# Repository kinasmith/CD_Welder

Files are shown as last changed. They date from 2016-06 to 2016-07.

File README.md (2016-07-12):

##Capacitive Discharge Welder

based off of this [project.](http://www.instructables.com/id/Capacitive-Discharge-CD-Welder-for-battery-tabs/) and this [project](http://zeva.com.au/Projects/SpotWelderV2/). 

Included in this repo is the Control code (for arduino Pro Mini), and the PCB files I used. The Capacitor Board is slightly too large for the free version of Eagle (sorry!).

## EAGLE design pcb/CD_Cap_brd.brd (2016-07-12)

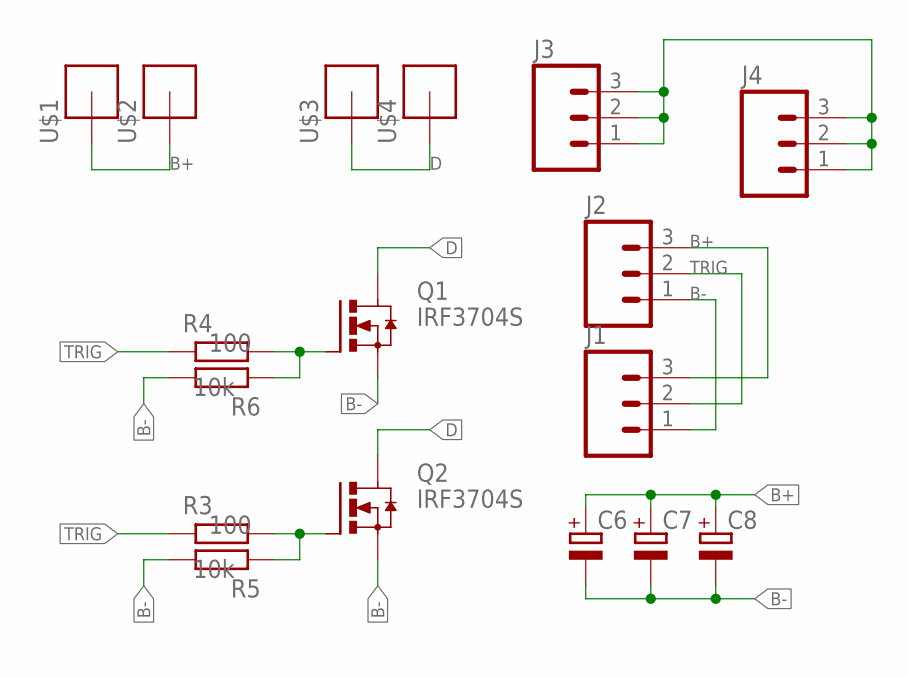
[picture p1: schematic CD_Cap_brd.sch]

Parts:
C6, C7, C8: CPOL-EUE10-35; EB35D
J1, J2: M03PTH; 1X03
J3, J4: M03LOCK; 1X03_LOCK
Q1, Q2: IRF3704S; D2PACK
R3, R4: 100; R0603-N
R5, R6: 10k; R0603-N
U$1, U$2, U$3, U$4: BIG_PINHEADX110-32; M6_PINHEAD

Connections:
B+: C6.+, C7.+, C8.+, J1.3, J2.3, U$1.P$1, U$2.P$1
B-: C6.-, C7.-, C8.-, J1.1, J2.1, J3.1, J3.2, J3.3, J4.1, J4.2, J4.3, Q1.3 (S), Q2.3 (S), R5.2, R6.2
D: Q1.2 (D), Q2.2 (D), U$3.P$1, U$4.P$1
unnamed: Q1.1 (G), R4.2, R6.1
unnamed: Q2.1 (G), R3.2, R5.1
TRIG: J1.2, J2.2, R3.1, R4.1

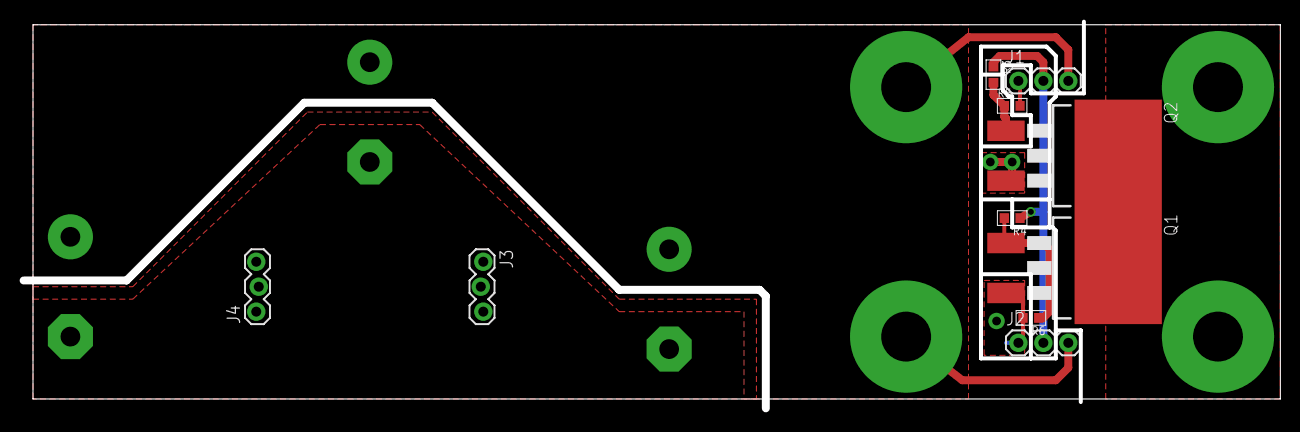
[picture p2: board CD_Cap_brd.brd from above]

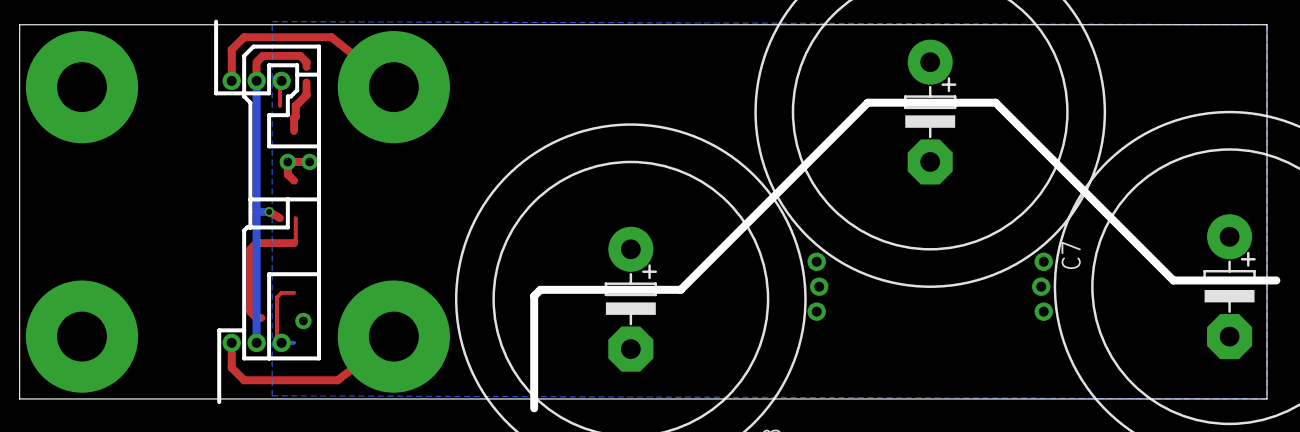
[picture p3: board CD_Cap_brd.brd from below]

Board: 2 copper layers, 128.0 x 39.4 mm, 17 parts (3 on the bottom side), 6 nets.

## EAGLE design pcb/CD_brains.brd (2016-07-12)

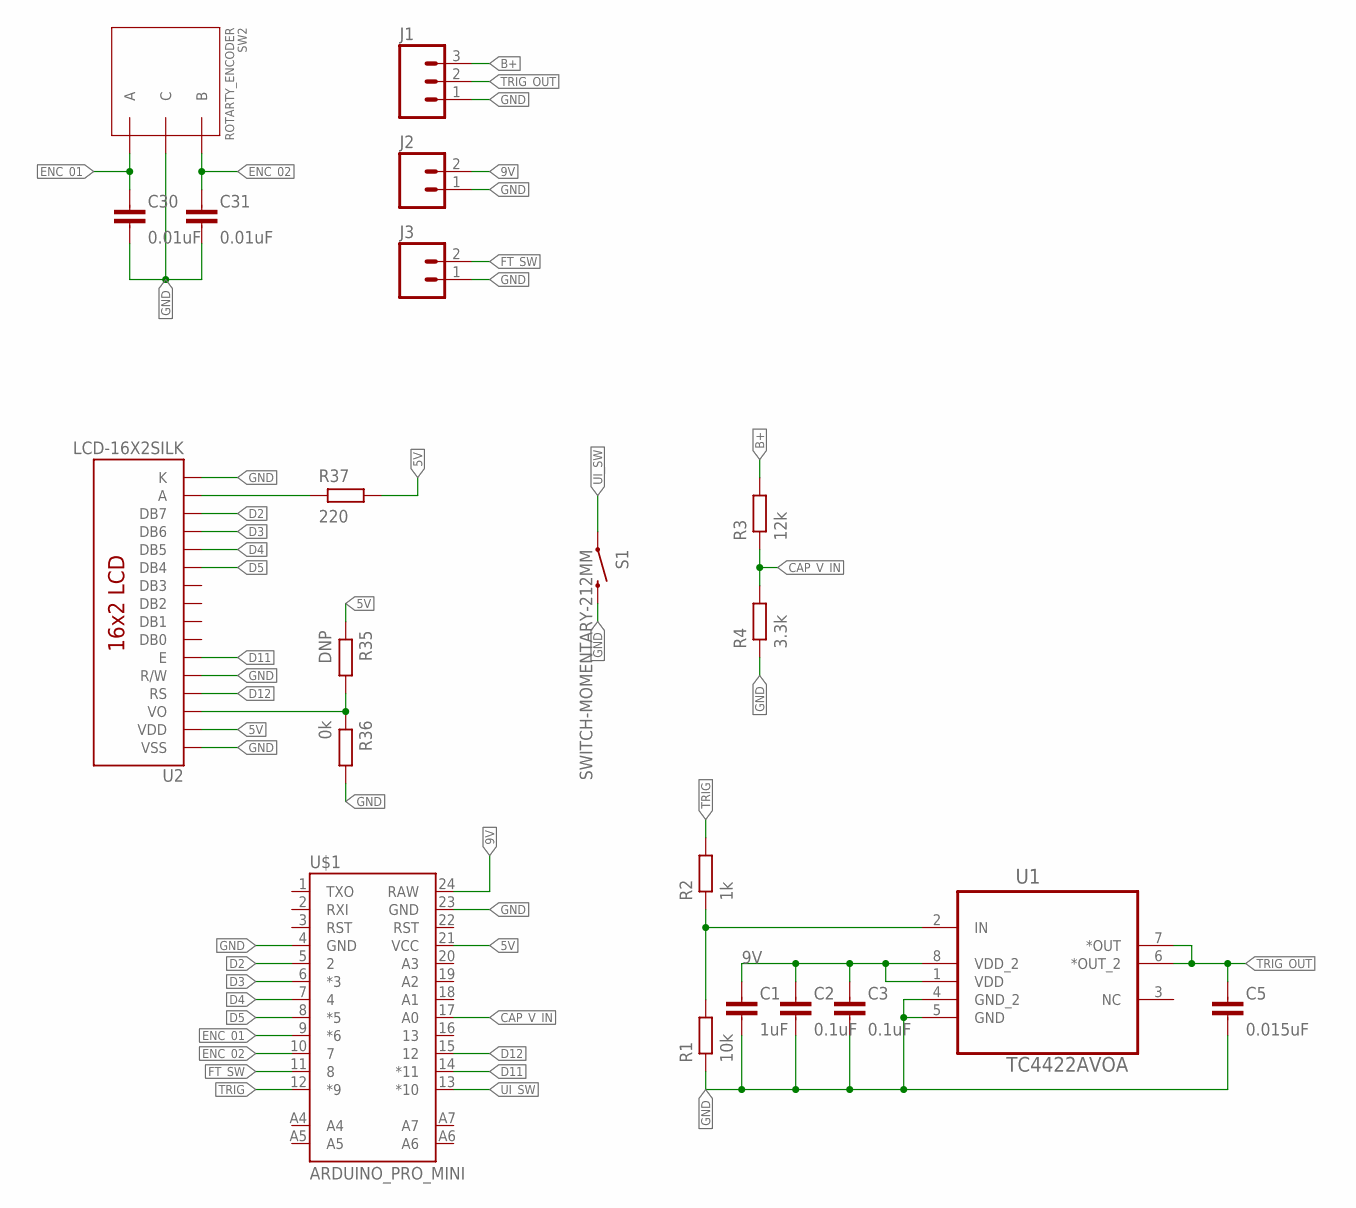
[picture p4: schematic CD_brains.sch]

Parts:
C1: 1uF; C0805-N
C2, C3: 0.1uF; C0603-N
C5: 0.015uF; C0603-N
C30, C31: 0.01uF; C0603-N
J1: M03LOCK_NO_SILK; 1X03_LOCK_NO_SILK
J2, J3: M02LOCK; 1X02_LOCK
R1: 10k; R0603-N
R2: 1k; R0603-N
R3: 12k; R0603-N
R4: 3.3k; R0603-N
R35: DNP; R0603-N
R36: 0k; R0603-N
R37: 220; R0603-N
S1: SWITCH-MOMENTARY-212MM; TACTILE-PTH-12MM
SW2: ROTARTY_ENCODER; ROTARY_ENC_PLAIN
U1: TC4422AVOA; SOIC127P600X175-8N
U2: LCD-16X2SILK; LCD-16X2
U$1: ARDUINO_PRO_MINI

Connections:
5V: R35.1, R37.2, U2.2 (VDD), U$1.21 (VCC)
9V: C1.1, C2.1, C3.1, J2.2, U1.1 (VDD), U1.8 (VDD_2), U$1.24 (RAW)
B+: J1.3, R3.2
CAP_V_IN: R3.1, R4.2, U$1.17 (A0)
D2: U2.14 (DB7), U$1.5 (2)
D3: U2.13 (DB6), U$1.6 (*3)
D4: U2.12 (DB5), U$1.7 (4)
D5: U2.11 (DB4), U$1.8 (*5)
D11: U2.6 (E), U$1.14 (*11)
D12: U2.4 (RS), U$1.15 (12)
ENC_01: C30.1, SW2.A, U$1.9 (*6)
ENC_02: C31.1, SW2.B, U$1.10 (7)
FT_SW: J3.2, U$1.11 (8)
GND: C1.2, C2.2, C3.2, C5.2, C30.2, C31.2, J1.1, J2.1, J3.1, R1.1, R4.1, R36.2, S1.3 (2), SW2.C, U1.4 (GND_2), U1.5 (GND), U2.1 (VSS), U2.5 (R/W), U2.16 (K), U$1.4 (GND), U$1.23 (GND)
unnamed: R1.2, R2.1, U1.2 (IN)
unnamed: R37.1, U2.15 (A)
unnamed: R35.2, R36.1, U2.3 (VO)
TRIG: R2.2, U$1.12 (*9)
TRIG_OUT: C5.1, J1.2, U1.6 (*OUT_2), U1.7 (*OUT)
UI_SW: S1.1, U$1.13 (*10)

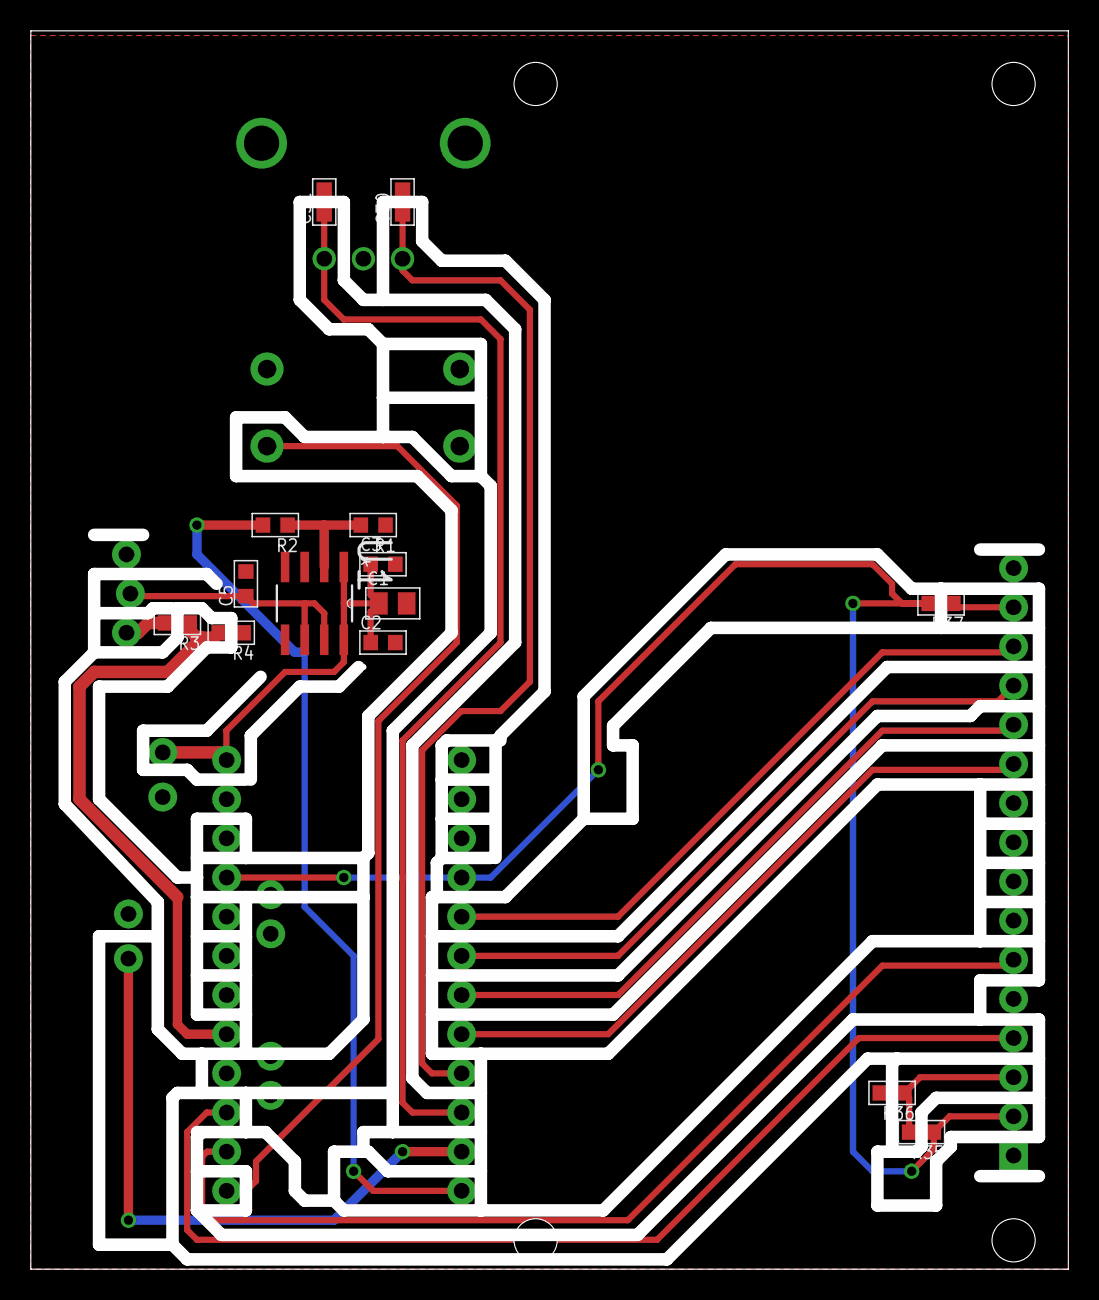
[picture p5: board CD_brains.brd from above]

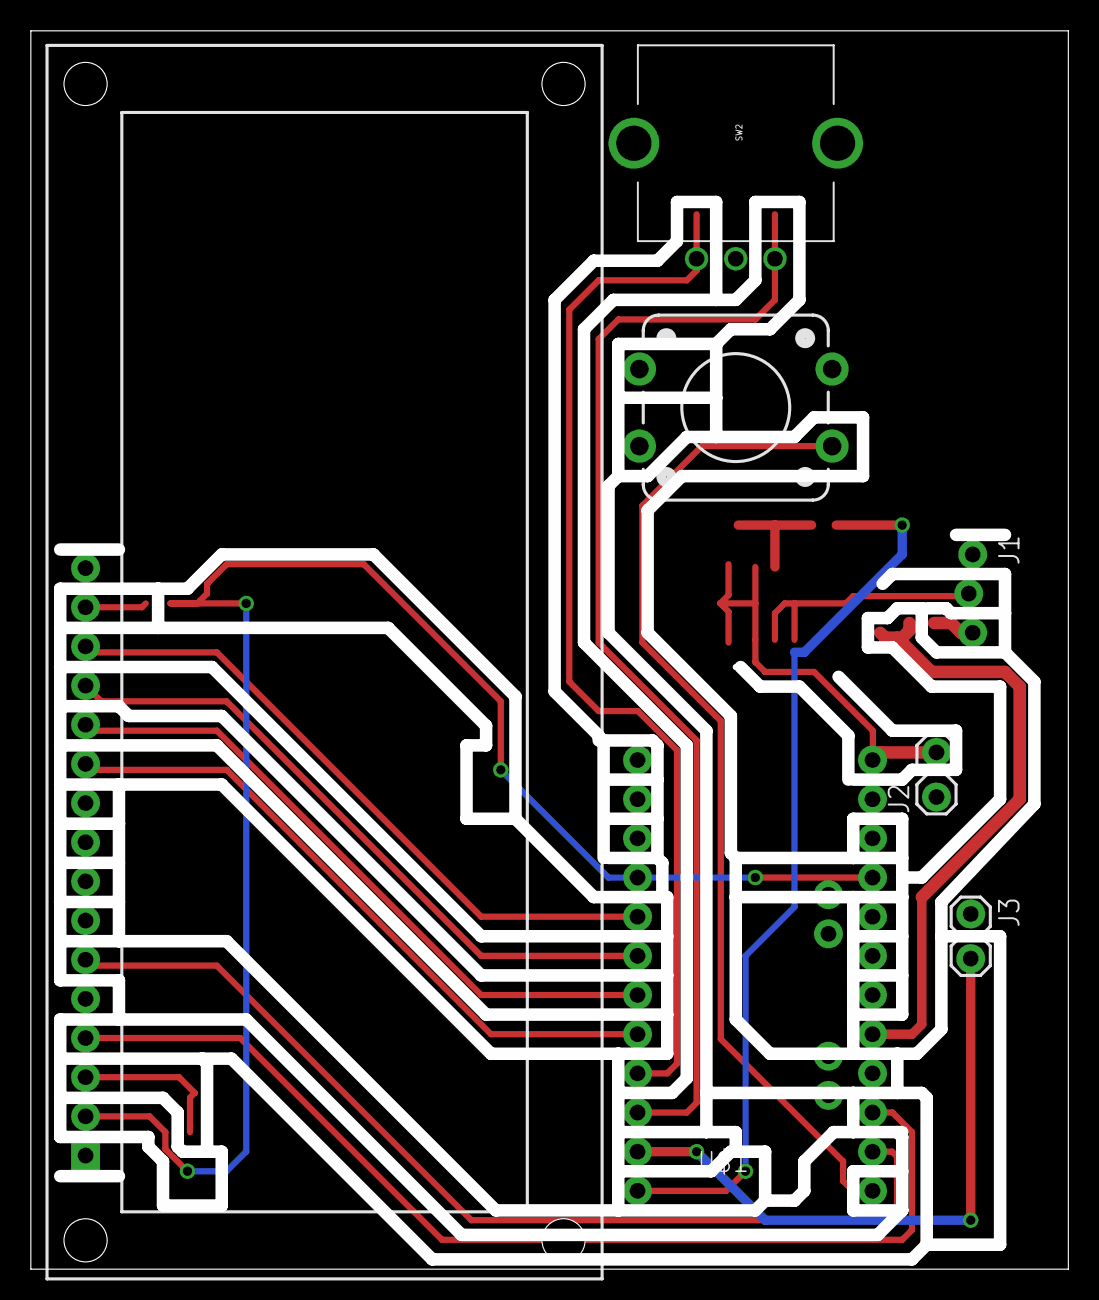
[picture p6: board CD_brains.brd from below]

Board: 2 copper layers, 67.3 x 80.3 mm, 21 parts (7 on the bottom side), 20 nets.

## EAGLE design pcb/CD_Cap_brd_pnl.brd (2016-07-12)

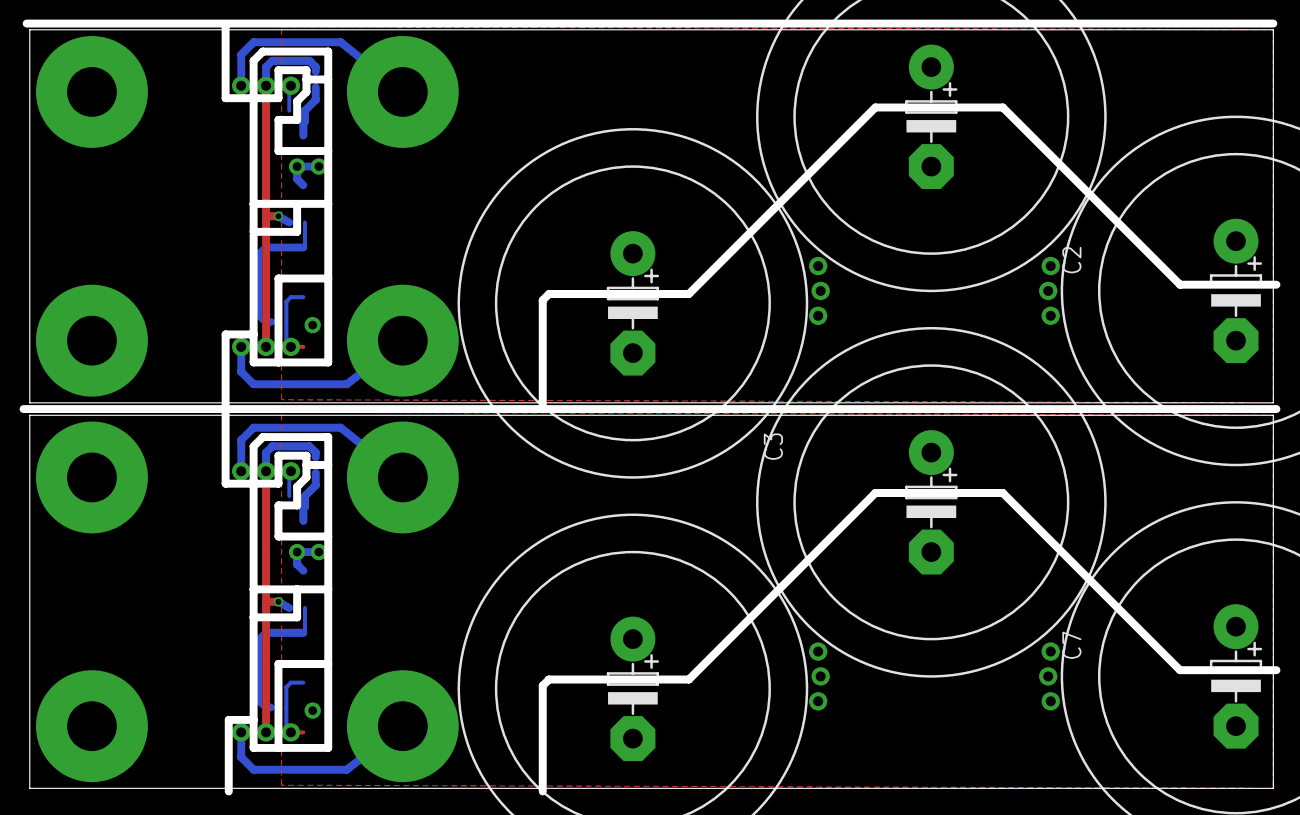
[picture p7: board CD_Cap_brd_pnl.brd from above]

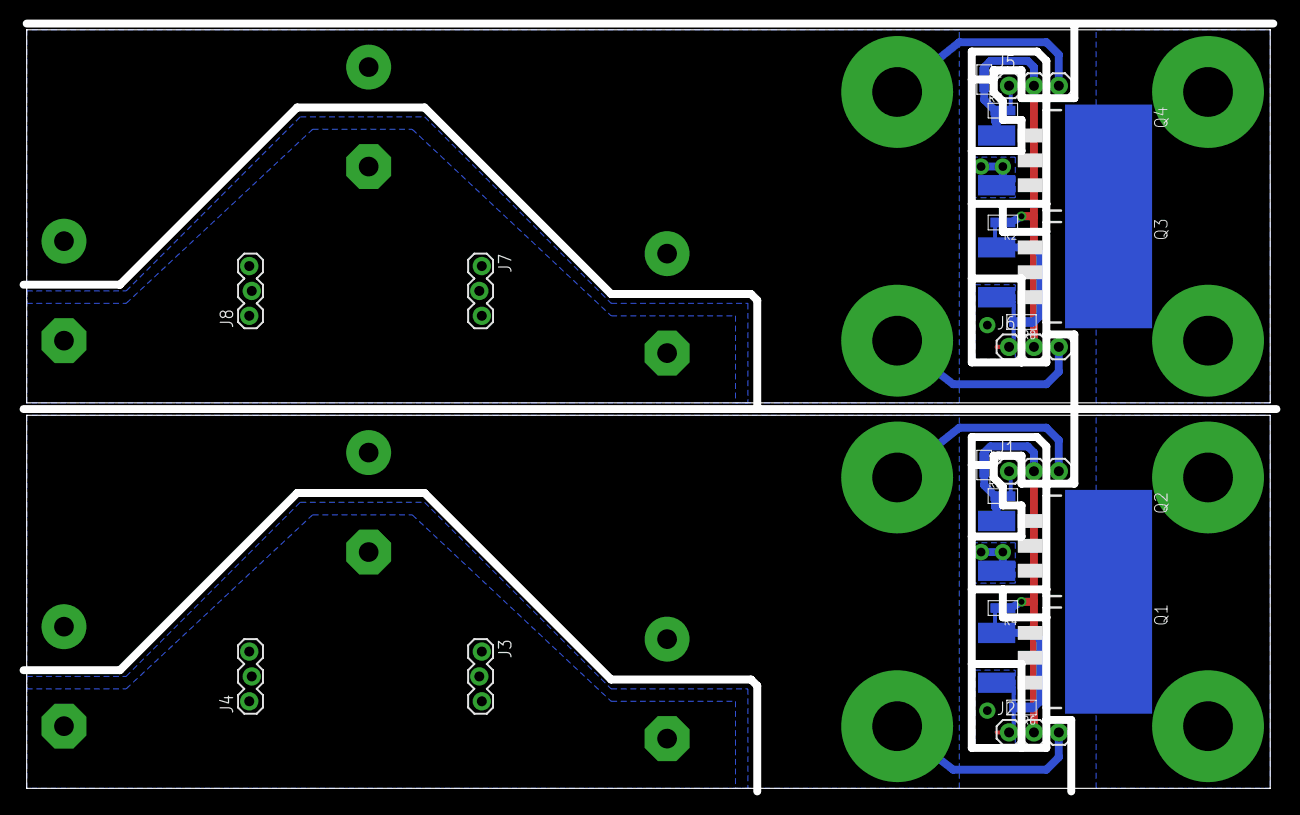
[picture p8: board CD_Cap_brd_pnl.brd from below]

Board: 2 copper layers, 128.0 x 78.4 mm, 34 parts (28 on the bottom side), 12 nets.

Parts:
C1, C2, C3, C6, C7, C8: EB35D
J1, J2, J5, J6: 1X03
J3, J4, J7, J8: 1X03_LOCK
Q1, Q2, Q3, Q4: IRF3704S; D2PACK
R1, R2, R3, R4: 100; R0603-N
R5, R6, R7, R8: 10k; R0603-N
U$1, U$2, U$3, U$4, U$5, U$6, U$7, U$8: BIG_PINHEADX110-32; M6_PINHEAD

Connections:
B+: C6.+, C7.+, C8.+, J1.3, J2.3, U$1.P$1, U$2.P$1
B+1: C1.+, C2.+, C3.+, J5.3, J6.3, U$5.P$1, U$6.P$1
B-: C6.-, C7.-, C8.-, J1.1, J2.1, J3.1, J3.2, J3.3, J4.1, J4.2, J4.3, Q1.3, Q2.3, R5.2, R6.2
B-1: C1.-, C2.-, C3.-, J5.1, J6.1, J7.1, J7.2, J7.3, J8.1, J8.2, J8.3, Q3.3, Q4.3, R7.2, R8.2
D: Q1.2, Q2.2, U$3.P$1, U$4.P$1
D1: Q3.2, Q4.2, U$7.P$1, U$8.P$1
unnamed: Q1.1, R4.2, R6.1
unnamed: Q4.1, R1.2, R7.1
unnamed: Q2.1, R3.2, R5.1
unnamed: Q3.1, R2.2, R8.1
TRIG: J1.2, J2.2, R3.1, R4.1
TRIG1: J5.2, J6.2, R1.1, R2.1

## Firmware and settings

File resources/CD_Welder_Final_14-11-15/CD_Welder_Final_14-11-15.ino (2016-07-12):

/*
Simons CD welder software - use at your own risk!!!

Inluding this great library for the LCD screen
******************************************************************************************8  
  Universal 8bit Graphics Library, http://code.google.com/p/u8glib/
  
  Copyright (c) 2012, olikraus@gmail.com
  All rights reserved.

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
  THIS SOFTWARE IS PROVIDED BY THE COPYRIGHT HOLDERS AND 
  CONTRIBUTORS "AS IS" AND ANY EXPRESS OR IMPLIED WARRANTIES, 
  INCLUDING, BUT NOT LIMITED TO, THE IMPLIED WARRANTIES OF 
  MERCHANTABILITY AND FITNESS FOR A PARTICULAR PURPOSE ARE 
  DISCLAIMED. IN NO EVENT SHALL THE COPYRIGHT HOLDER OR 
  CONTRIBUTORS BE LIABLE FOR ANY DIRECT, INDIRECT, INCIDENTAL, 
  SPECIAL, EXEMPLARY, OR CONSEQUENTIAL DAMAGES (INCLUDING, BUT 
  NOT LIMITED TO, PROCUREMENT OF SUBSTITUTE GOODS OR SERVICES; 
  LOSS OF USE, DATA, OR PROFITS; OR BUSINESS INTERRUPTION) HOWEVER 
  CAUSED AND ON ANY THEORY OF LIABILITY, WHETHER IN CONTRACT, 
  STRICT LIABILITY, OR TORT (INCLUDING NEGLIGENCE OR OTHERWISE) 
  ARISING IN ANY WAY OUT OF THE USE OF THIS SOFTWARE, EVEN IF 
  ADVISED OF THE POSSIBILITY OF SUCH DAMAGE.  
**********************************************************************************************  
*  
*/


#include "U8glib.h"

// setup u8g object, please remove comment from one of the following constructor calls
// IMPORTANT NOTE: The following list is incomplete. The complete list of supported 
// devices with all constructor calls is here: http://code.google.com/p/u8glib/wiki/device
U8GLIB_ST7920_128X64_1X u8g(13, 11, 12);	// SPI Com: SCK = en = 18, MOSI = rw = 16, CS = di = 17

#define u8g_logo_width 94
#define u8g_logo_height 64
//static unsigned char u8g_logo_bits[] = {
static unsigned char u8g_logo_bits[] U8G_PROGMEM = {
0x00, 0x00, 0x00, 0x00, 0x00, 0xfc, 0x01, 0x00, 0x00, 0x00, 0x00, 0xc0, 
0x00, 0x00, 0x00, 0x00, 0x80, 0xff, 0x1f, 0x00, 0x00, 0x00, 0x00, 0xc0, 
0x00, 0x00, 0x00, 0x00, 0xe0, 0xff, 0x7f, 0x00, 0x00, 0x00, 0x00, 0xc0, 
0x00, 0x00, 0x00, 0x00, 0xf8, 0xff, 0xff, 0x00, 0x00, 0x00, 0x00, 0xc0, 
0x00, 0x00, 0x00, 0x00, 0xfc, 0xff, 0xff, 0x01, 0x00, 0x00, 0x00, 0xc0, 
0x00, 0x00, 0x00, 0x00, 0xfc, 0x3f, 0xe0, 0x03, 0x00, 0x00, 0x00, 0xc0, 
0x00, 0x00, 0x00, 0x00, 0xfe, 0x33, 0xe0, 0x03, 0x00, 0x00, 0x00, 0xc0, 
0x00, 0x00, 0x00, 0x00, 0xfe, 0xff, 0xff, 0x07, 0x00, 0x00, 0x00, 0xc0, 
0x00, 0x00, 0x00, 0x00, 0xfe, 0xff, 0xff, 0x07, 0x00, 0x00, 0x00, 0xc0, 
0x00, 0x00, 0x00, 0x00, 0xfe, 0xff, 0xff, 0x07, 0x00, 0x00, 0x00, 0xc0, 
0x00, 0x00, 0x00, 0x00, 0xfe, 0xff, 0xff, 0x07, 0x00, 0x00, 0x00, 0xc0, 
0x00, 0x00, 0x00, 0x00, 0xfe, 0xff, 0xff, 0x07, 0x00, 0x00, 0x00, 0xc0, 
0x00, 0x00, 0x00, 0x00, 0xfe, 0xff, 0xff, 0x07, 0x00, 0x00, 0x00, 0xc0, 
0x00, 0x00, 0x00, 0x00, 0xfe, 0xff, 0xff, 0x0f, 0x00, 0x00, 0x00, 0xc0, 
0x00, 0x00, 0x00, 0x00, 0xfe, 0xff, 0xff, 0x0f, 0x00, 0x00, 0x00, 0xc0, 
0x00, 0x00, 0x00, 0x00, 0x3f, 0x00, 0x80, 0x0f, 0x00, 0x00, 0x00, 0xc0, 
0x00, 0x00, 0x00, 0x00, 0x9f, 0xff, 0xbf, 0x0f, 0x00, 0x00, 0x00, 0xc0, 
0x00, 0x00, 0x00, 0x00, 0x9f, 0xdf, 0xbf, 0x0f, 0x00, 0x00, 0x00, 0xc0, 
0x00, 0x00, 0x00, 0x00, 0x9f, 0x7b, 0xbb, 0x0f, 0x00, 0x00, 0x00, 0xc0, 
0x00, 0x00, 0x00, 0x00, 0x9f, 0x7d, 0xb7, 0x0f, 0x00, 0x00, 0x00, 0xc0, 
0x00, 0x00, 0x00, 0x00, 0x9f, 0x03, 0xb8, 0x0f, 0x00, 0x00, 0x00, 0xc0, 
0x00, 0x00, 0x00, 0x00, 0xbf, 0x02, 0xd0, 0x1f, 0x00, 0x00, 0x00, 0xc0, 
0x00, 0x00, 0x00, 0x7f, 0xbf, 0xff, 0xdf, 0xff, 0x0f, 0x00, 0x00, 0xc0, 
0x00, 0x00, 0xc0, 0x7f, 0x7f, 0x00, 0xc0, 0xff, 0x3f, 0x00, 0x00, 0xc0, 
0x00, 0x00, 0xe0, 0x7f, 0xff, 0xff, 0xff, 0xff, 0xff, 0x00, 0x00, 0xc0, 
0x00, 0x00, 0xf8, 0xff, 0xff, 0xff, 0xff, 0xdf, 0xff, 0x03, 0x00, 0xc0, 
0x00, 0x00, 0xfe, 0xff, 0xbf, 0xff, 0xff, 0xdf, 0xff, 0x07, 0x00, 0xc0, 
0x00, 0x00, 0xfe, 0xff, 0xff, 0xff, 0xde, 0xdb, 0xff, 0x1f, 0x00, 0xc0, 
0x00, 0x80, 0xff, 0xef, 0x7f, 0xfd, 0xfe, 0xdb, 0xff, 0x3f, 0x00, 0xc0, 
0x00, 0xe0, 0xff, 0xdf, 0x7f, 0xf6, 0xfe, 0xdb, 0xff, 0x7f, 0x00, 0xc0, 
0x00, 0xf0, 0xff, 0xbd, 0xff, 0xf2, 0xbe, 0xf9, 0xef, 0xff, 0x01, 0xc0, 
0x00, 0xfc, 0xff, 0x3b, 0xff, 0xac, 0xb6, 0xfc, 0xf7, 0xff, 0x07, 0xc0, 
0x00, 0xff, 0xff, 0x77, 0xd6, 0x48, 0x94, 0xf4, 0xf9, 0xff, 0x0f, 0xc0, 
0xc0, 0xff, 0xff, 0x6f, 0xac, 0x41, 0x54, 0xfc, 0xbc, 0xff, 0x7f, 0xc0, 
0xf0, 0xff, 0xff, 0xff, 0x48, 0x01, 0x40, 0x3c, 0xde, 0xff, 0xff, 0xc1, 
0xf8, 0xff, 0x7f, 0xff, 0x11, 0x00, 0x00, 0x18, 0xff, 0xff, 0xff, 0xc3, 
0xfc, 0xff, 0xff, 0xdf, 0x01, 0x00, 0x00, 0x80, 0xfd, 0xff, 0xff, 0xc7, 
0xfc, 0xff, 0xff, 0xbf, 0x03, 0x00, 0x00, 0x80, 0xff, 0xff, 0xff, 0xcf, 
0xfe, 0xff, 0xff, 0x5f, 0x02, 0x00, 0x00, 0xc0, 0xff, 0xfe, 0xff, 0xdf, 
0xfe, 0xff, 0xff, 0xf0, 0x00, 0x00, 0x00, 0xe0, 0x30, 0xff, 0xff, 0xdf, 
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
};

int divVoltagePin = A0;    // select the input pin for the potentiometer
int divVoltageValue = 0;  // variable to store the value coming from the sensor

int pot1 = A4;    // select the input pin for the potentiometer for pulse 1
int pot2 = A5;    // select the input pin for the potentiometer for the dwell
int pot3 = A6;    // select the input pin for the potentiometer for pulse 2

int pulse1Value = 0;  // variable to hold the potentiometer value
int dwellValue = 0;  // variable to hold the potentiometer value
int pulse2Value = 0;  // variable to hold the potentiometer value

const int buttonPin = 4;     // the number of the pushbutton pin
const int buzz = 5;

const int numReadings = 10;  // use this value to determine the size of the readings array.
int voltageReadings[numReadings];      // the readings from the analog input
int voltageReadIndex = 0;              // the index of the current reading
float voltageTotal = 0;                  // the running total
float voltageAverage = 0.0;            // the average
float voltageAverageOld = 0.0;          // the old voltage average reading

boolean voltageSteady = false;    //boolean to monitor whether the voltage is fluctuating - a weld can only be performed when the voltage is stable

const int gatePin = 6; // the number of the gate trigger pulse

int weldComplete = 1;
int buttonState = 0;         // variable for reading the pushbutton status

char* statusText[2] = {"Stabalising volts", "*Ready to weld*"};  // text for the screen to indicate readiness for welding
int  statusTextNum = 0;



void draw(void) {
  // graphic commands to redraw the complete screen should be placed here  

  u8g.setPrintPos(0, 10); 
  u8g.print("Pulse 1 ="); 
  u8g.setPrintPos(80, 10); 
  u8g.print(pulse1Value/10.0);
  u8g.setPrintPos(0, 23); 
  u8g.print("Dwell   = "); 
  u8g.setPrintPos(80, 23); 
  u8g.print(dwellValue/10.0);
  u8g.setPrintPos(0, 36); 
  u8g.print("Pulse 2 ="); 
  u8g.setPrintPos(80, 36); 
  u8g.print(pulse2Value/10.0);
  u8g.setPrintPos(0, 49);
  u8g.print("Cap Volts ="); 
  u8g.setPrintPos(90, 49);
  float voltage = voltageAverage * (5.0/1023.0) * 3.0 +.05; // Calculate the voltage across the divider, the +0.05 is the difference between my reading on a DMM and the arduino - not a bad corralation
  u8g.print(voltage);
  u8g.setPrintPos(0, 62);
  u8g.print(statusText[statusTextNum]);
}

void setup(void) {

  Serial.begin(115200);
  // flip screen, if required
  // u8g.setRot180();

  // initialize the pushbutton pin as an input:
  pinMode(buttonPin, INPUT_PULLUP);
  pinMode(gatePin, OUTPUT);
  pinMode(buzz, OUTPUT);
    u8g.firstPage();
  do { 
  u8g.drawXBMP( 15, 11, u8g_logo_width, u8g_logo_height, u8g_logo_bits);
  u8g.setFont(u8g_font_unifont);
  //u8g.setFont(u8g_font_osb21);
  u8g.drawStr( 0, 10, "Simons CD Welder");
   } while( u8g.nextPage() );

  delay (2000);
    // initialize all the readings to 0:
  for (int thisReading = 0; thisReading < numReadings; thisReading++) {
    voltageReadings[thisReading] = 0;
  }
  
}

void weldschedule() {

  digitalWrite(gatePin, HIGH);
  delay (pulse1Value/10);
  digitalWrite(gatePin, LOW);
  delay (dwellValue/10);
  digitalWrite(gatePin, HIGH);
  delay (pulse2Value/10);
  digitalWrite(gatePin, LOW);
  weldComplete = 1;
  digitalWrite(buzz, HIGH);
  delay (200);
  digitalWrite(buzz, LOW);
  
}

void loop(void) {
  
  // picture loop
  u8g.firstPage();  
  do {
    draw();
  } while( u8g.nextPage() );
  
  pulse1Value = analogRead(pot1);
  dwellValue = analogRead(pot2);
  pulse2Value = analogRead(pot3);
  
  // read the voltage from the voltage divider
  // subtract the last reading:
  voltageTotal = voltageTotal - voltageReadings[voltageReadIndex];
  // read from the sensor:
  voltageReadings[voltageReadIndex] = analogRead(divVoltagePin);
  // add the reading to the total:
  voltageTotal = voltageTotal + voltageReadings[voltageReadIndex];
  // advance to the next position in the array:
  voltageReadIndex = voltageReadIndex + 1;

  // if we're at the end of the array...
  if (voltageReadIndex >= numReadings) {
    // ...wrap around to the beginning:
    voltageReadIndex = 0;
  }

  // calculate the average:
  voltageAverage = voltageTotal / numReadings;
  float voltageDiff = voltageAverageOld - voltageAverage;
  Serial.println (voltageDiff);
  if (voltageDiff <= 0.3 && voltageDiff >= -0.3  && weldComplete == 1) {
  weldComplete = 0; 
  voltageSteady = true;
  for (int i= 1 ;i < 4; i ++){
    digitalWrite(buzz, HIGH);
    delay (50);
    digitalWrite(buzz, LOW);
    delay (50);
    statusTextNum = 1;
   }
 }
 
 if (voltageDiff >= 0.5 || voltageDiff <= -0.5){

  voltageSteady = false;
  weldComplete = 1;
  statusTextNum = 0;
 }
  Serial.println(voltageAverageOld);
  Serial.println(voltageAverage);
  voltageAverageOld = voltageAverage;
  pulse1Value = map(pulse1Value, 0 , 1023, 0, 300);      // re-map pot 1 to 0 - XX pulse length
  dwellValue = map(dwellValue, 0 , 1023, 0, 200);      // re-map pot 1 to 0 - XX pulse length
  pulse2Value = map(pulse2Value, 0 , 1023, 0, 1000);      // re-map pot 1 to 0 - XX pulse length

  // read the state of the pushbutton value:
  buttonState = digitalRead(buttonPin);
  //Serial.println(buttonState);
  //Serial.println(weldComplete);
  //Serial.println(voltageSteady);
  //Serial.println("");
  // check if the pushbutton is pressed.
  // if it is, the buttonState is HIGH:
  
  if (buttonState == LOW && weldComplete == 0 && voltageSteady == true) {
  // complete a weld:
  //  Serial.println("Do a weld now!");
    weldschedule();
  }
    delay(10);        // delay in between reads for stability
}

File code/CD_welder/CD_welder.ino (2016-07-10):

#define ENCODER_DO_NOT_USE_INTERRUPTS

#include "Encoder.h"
#include "LiquidCrystal.h"
#include "Bounce2.h"

const int UI_SW = 10;
const int FT_SW = 8;
const int LED = 13;
const int CAP_V_INPUT = 0;
const int TRIG = 9;
const float div_z1_val = 11990;
const float div_z2_val = 3227;

//vOut = z2/(z1+z2) * vIn

Encoder myEnc(6, 7);
Bounce UI_SW_input = Bounce();
Bounce FT_SW_input = Bounce();
LiquidCrystal lcd(12, 11, 5, 4, 3, 2);

int pulse1Time = 100;
int dwellTime = 100;
int pulse2Time = 100;

float capVoltage = 0;

const int numReadings = 10;  // use this value to determine the size of the readings array.
int voltageReadings[numReadings];      // the readings from the analog input
int voltageReadIndex = 0;              // the index of the current reading
float voltageTotal = 0;                  // the running total
float voltageAverage = 0.0;            // the average
float voltageAverageOld = 0.0;          // the old voltage average reading

boolean voltageSteady = false;    //boolean to monitor whether the voltage is fluctuating - a weld can only be performed when the voltage is stable
int weldComplete = 1;

char* statusText[2] = {"Stabalising volts", "*Ready to weld*"};  // text for the screen to indicate readiness for welding
int  statusTextNum = 0;

int displayUpdateInterval = 500;
long lastUpdate = 0;

int positionCounter = 0;
long encoderPosition  = 100;

void setup() {
  Serial.begin(9600);
  pinMode(LED, OUTPUT);
  pinMode(TRIG, OUTPUT);
  pinMode(UI_SW, INPUT_PULLUP);
  pinMode(FT_SW, INPUT_PULLUP);
  UI_SW_input.attach(UI_SW);
  UI_SW_input.interval(5);
  FT_SW_input.attach(FT_SW);
  FT_SW_input.interval(5);

  lcd.begin(16, 2);
  lcd.print("Electrocution!");
  delay(1000);
  lcd.cursor();
}

void loop() {
  UI_SW_input.update();
  FT_SW_input.update();
  capVoltage = (analogRead(CAP_V_INPUT) / 1024.0 * 5.0) / (div_z2_val / (div_z1_val + div_z2_val));
  if (UI_SW_input.fell()) {
    positionCounter++;
    positionCounter %= 3;
  }
  if (FT_SW_input.fell()) {
    weldSchedule();
  }
  updateDisplay();
  updateEncoder();
}

void updateDisplay() {
  if (millis() > lastUpdate + displayUpdateInterval) {
    lcd.clear();
    lcd.setCursor(0, 0);
    lcd.print("p1");
    lcd.setCursor(3, 0);
    lcd.print(pulse1Time);

    lcd.setCursor(0, 1);
    lcd.print("p2");
    lcd.setCursor(3, 1);
    lcd.print(pulse2Time);

    lcd.setCursor(7, 0);
    lcd.print("dw");
    lcd.setCursor(10, 0);
    lcd.print(dwellTime);

    lcd.setCursor(7, 1);
    lcd.print("cV");
    lcd.setCursor(10, 1);
    lcd.print(capVoltage);
    switch (positionCounter) {
      case 0:
        lcd.setCursor(2, 0);
        break;
      case 1:
        lcd.setCursor(2, 1);
        break;
      case 2:
        lcd.setCursor(9, 0);
        break;
    }
    lastUpdate = millis();
  }
}

void updateEncoder() {
  long newPos = myEnc.read();
  if (newPos != encoderPosition) {
    encoderPosition = newPos;
    switch (positionCounter) {
      case 0:
        pulse1Time = encoderPosition / 4;
        break;
      case 1:
        pulse2Time = encoderPosition / 4;
        break;
      case 2:
        dwellTime = encoderPosition / 4;
        break;
    }
  }
}

void weldSchedule() {
  digitalWrite(TRIG, HIGH);
  delay(pulse1Time/10);
  digitalWrite(TRIG, LOW);
  delay(dwellTime/10);
  digitalWrite(TRIG, HIGH);
  delay(pulse2Time/10);
  digitalWrite(TRIG, LOW);
}

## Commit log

2016-06-28 bunch of circuit stuff done
    [CD_Cap_brd.brd, CD_Cap_brd.sch, CD_Welder.brd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]
2016-06-29 almost ready for FAB
    [CD_Cap_brd.brd, CD_Cap_brd.sch]
2016-06-29 first circuit Fab: Success
    [CD_Cap_brd.brd, CD_Cap_brd.sch]
2016-07-09 finished the circuits etc.
    [CD_CONTROL_BRD.brd, CD_CONTROL_BRD.sch, CD_Cap_brd_pnl.brd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]
2016-07-10 finished code. Removed the Diode/Resistor Block...was causing mosfets to latch on
    [CD_CONTROL_BRD.sch]
2016-07-12 fixed CD BRAINS Inconsistencies
    [CD_Cap_brd_pnl.brd, CD_Cap_brd_pnl_lck.brd, CD_Diode_Bleed_Resistor_brd.brd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]
2016-07-12 minor stuff
    [CD_Cap_brd.brd, CD_Cap_brd.sch, CD_Cap_brd_pnl.brd]

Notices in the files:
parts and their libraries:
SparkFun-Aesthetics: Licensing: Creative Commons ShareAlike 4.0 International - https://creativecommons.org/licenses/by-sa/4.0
